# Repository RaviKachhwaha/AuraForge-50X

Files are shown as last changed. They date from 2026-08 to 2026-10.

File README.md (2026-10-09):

<h1 align="center">
  <br>
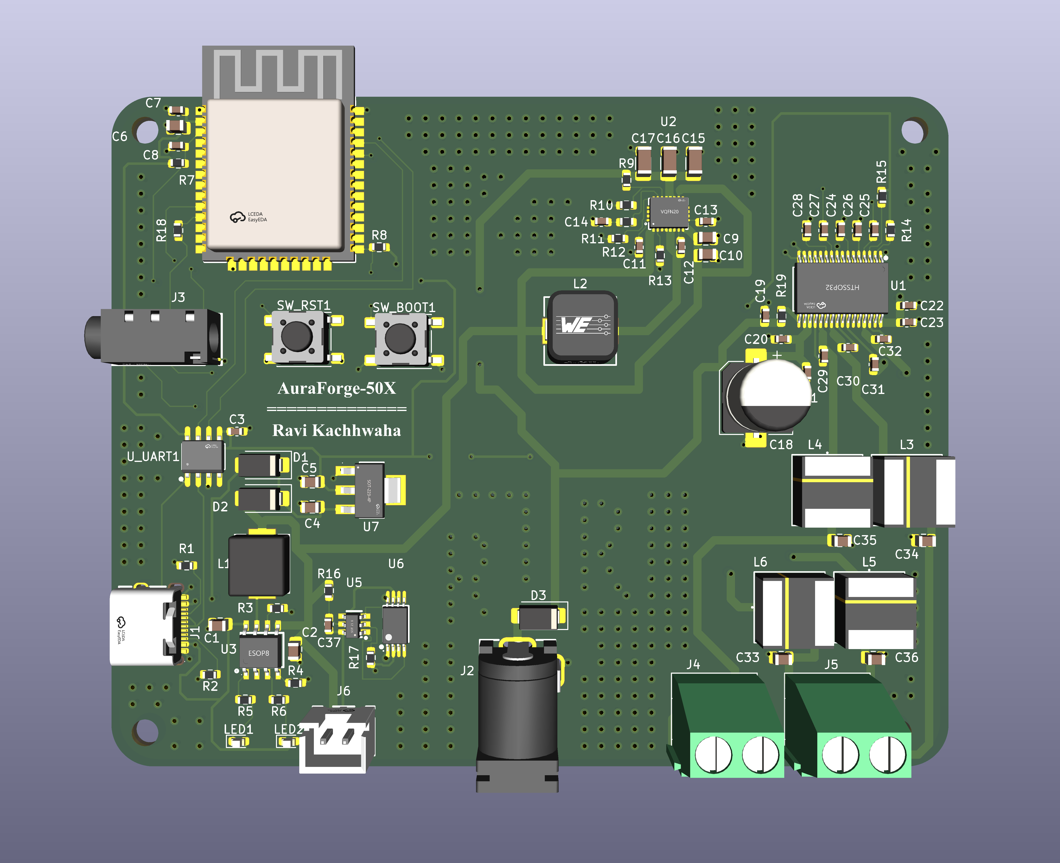
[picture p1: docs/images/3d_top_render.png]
  

  <br>
  AuraForge-50X
  <br>
</h1>
<h3 align="center">
A fully open-sourced complete wireless sound computer. 
</h3>

| Front Render | Back Render | 
| --- | --- |
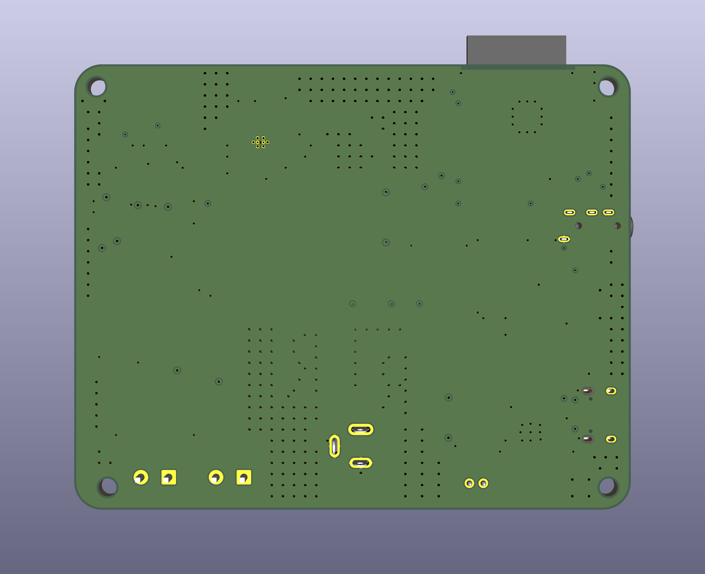
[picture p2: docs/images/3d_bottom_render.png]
|  |  | 

## Schematics  

Here are the schematic design,

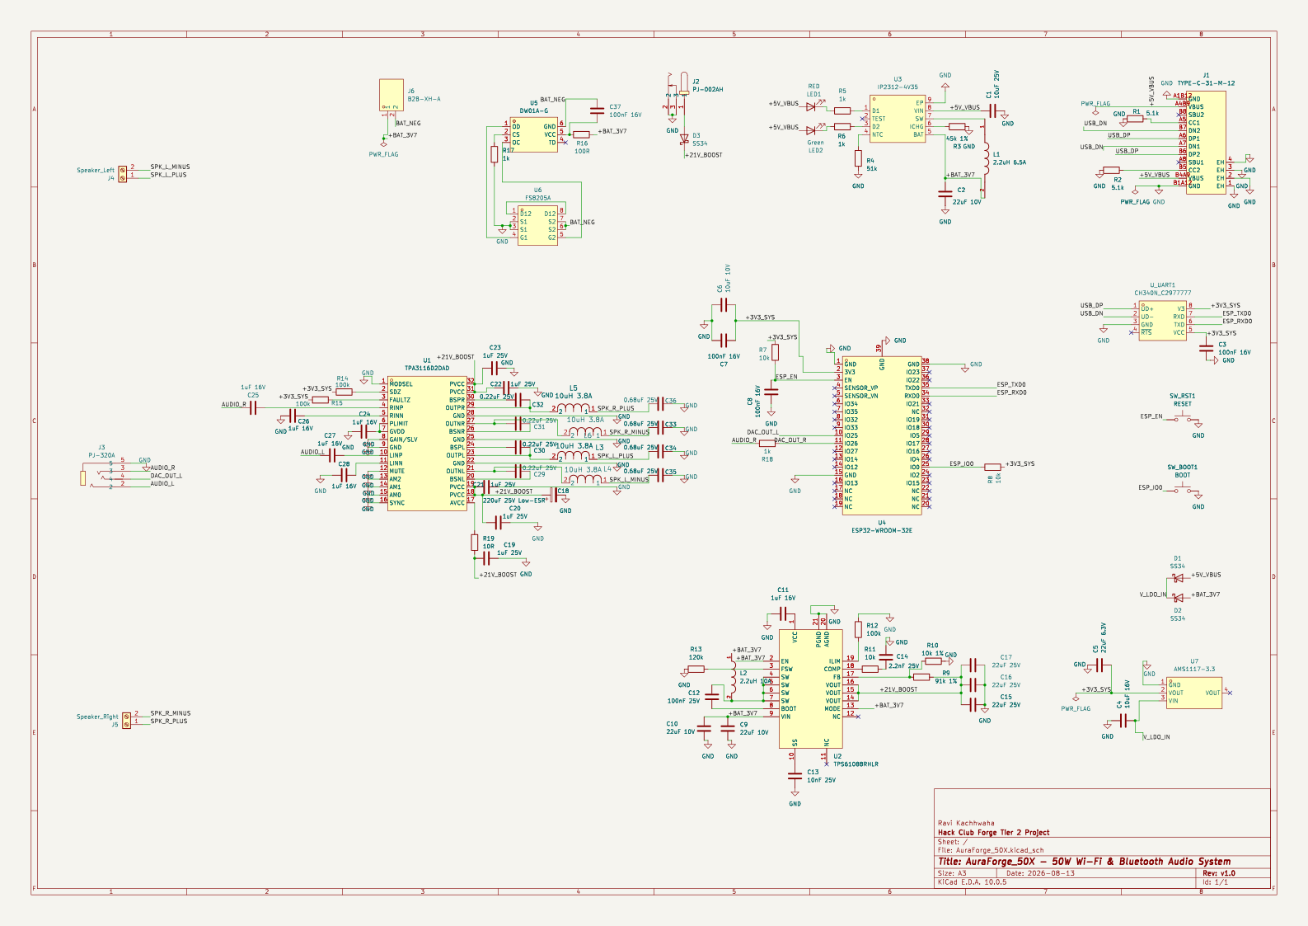
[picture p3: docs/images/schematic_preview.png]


## Features
- **ESP32-WROOM-32E MCU** - Dual-core Xtensa LX6, adjustable from 80 MHz to 240 MHz.
- **A 50Hz Wi-Fi CSI radar and real time DSP**.
- **TPA3116D2 Class-D amp**.
- **3A fast charging with BMS and Li-ion/LiPo both Battery support**.
- Power and battery indicator LED.
- Cyberpunk Web HUD.
- **USB C** - for programming.
- A 12-21V DC jack for power.

## PCB Design 
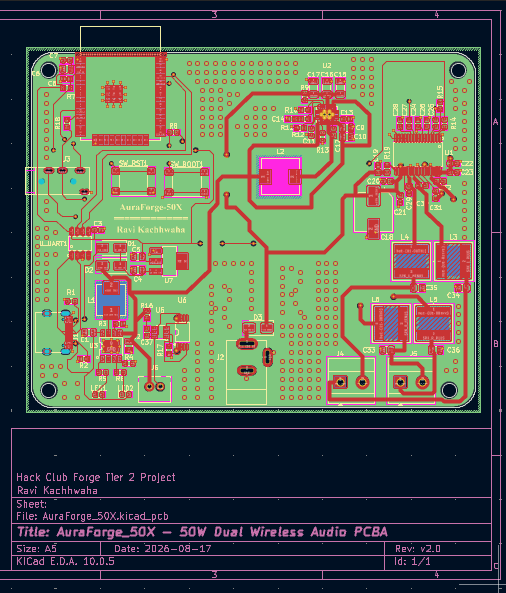
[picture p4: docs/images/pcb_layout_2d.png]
|  |
|--- |  

 ### The PCB is 4 layers with dimensions 100x80mm, made to be easily useable for anyone.  

 ### All the PCB files are [here](https://github.com/RaviKachhwaha/AuraForge-50X/blob/main/hardware) 

| Front Layer | Inner Layer 1 |
| --- | --- |
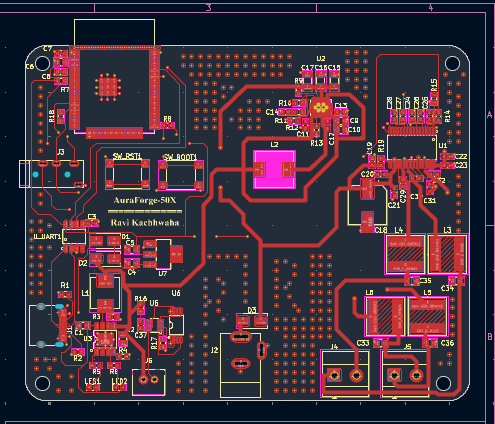
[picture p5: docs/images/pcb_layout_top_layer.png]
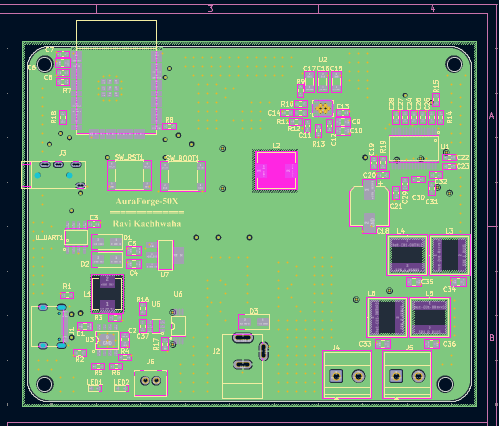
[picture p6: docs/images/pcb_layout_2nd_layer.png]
|  |  |
| Inner Layer 2 | Bottom layer |
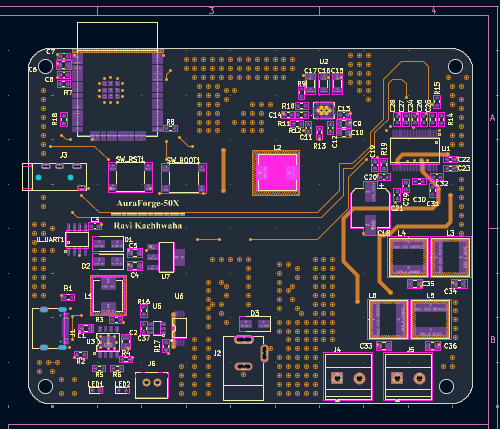
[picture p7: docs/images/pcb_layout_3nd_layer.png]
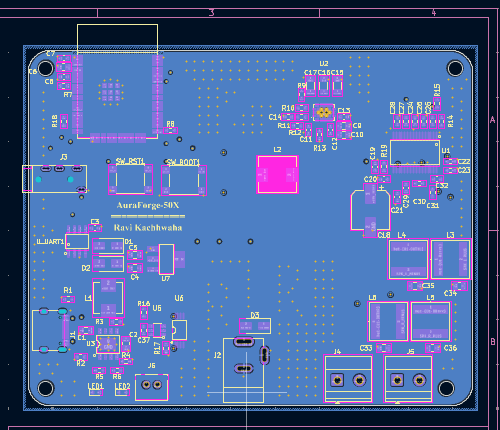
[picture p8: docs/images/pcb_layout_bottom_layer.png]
|  |  |

## Pinout  

This is a general pinout 

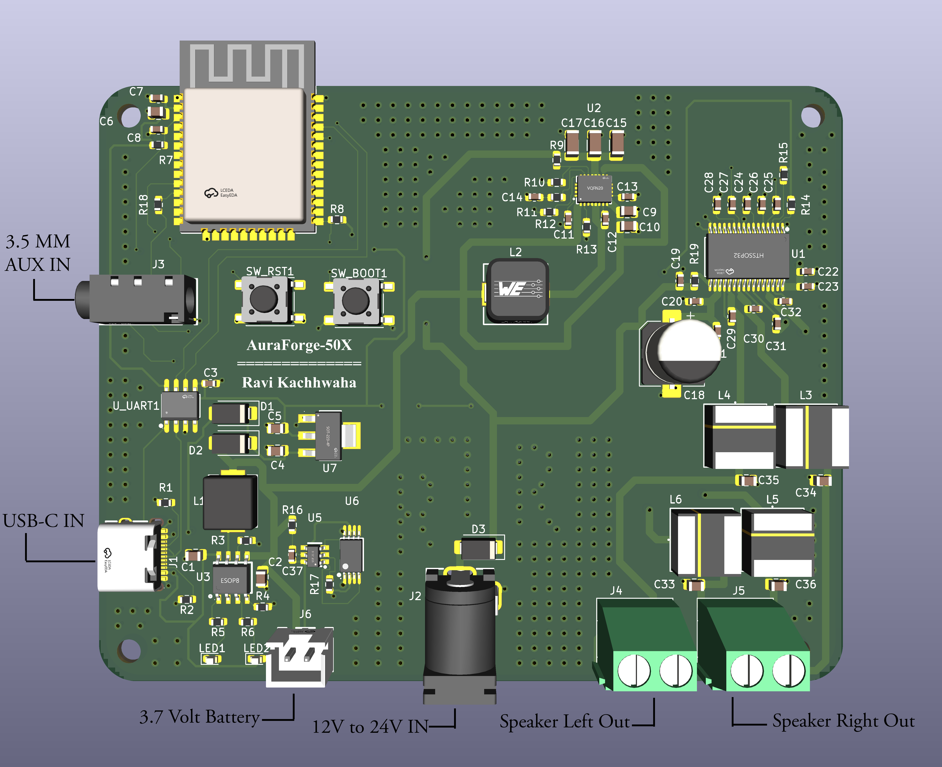
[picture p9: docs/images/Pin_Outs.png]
|  | 
| --- | 

(Credits to the KiCad EDA for KICAD 10, Espressif Systems for the MCU, RuView for CSI processing and Hack Club for fund to make this possible.) 

(Thanks to Madhav, tty7 to review my Design and tell me some mistakes like the antenna is pleased on board without open air due to that the range of it is low after the review from them I places the antenna in open air to get full range of Bluetooth and correct Wi-Fi CSI) 

## Why was it made?  

While using the normal Bluetooth amp for my many projects and in daily need, I realised it doesn't have Wi-Fi and high power support and I couldn't use it, unfortunately I had to think to buy a different high power amp then I see that those have high power but not Wi-Fi support and use very low price components which give low quality, but now I designed one with the simplicity of ESP32-WROOM-32E with being able to use Wi-Fi and Bluetooth both and also Programing support in a same board with high quality audio support for amp IC and have too many features.

## How you can get one for yourself? 

That is pretty easy, you have all the files you will need in the production folder, order the development  
board from any PCB fab ( I chose PCB Power cause its cheap in India and has good quality and also made in India ) and BINGO! You will have it to use for any purpose you want!  

## How do you use it?  
You can use it as any normal amp board but first want to flash the firmware which is given in firmware folder, for flashing you need to first enter the boootloader mode by holding the BOOT buttom and one time press and release the RESET button while connecting to your device, flash it with firmware and after all flashing done press the RESET button one time and you are good to go!
I have attached a simple firmware to start with prebuild firmware available in the firmware folder.  

## BOM  
|Name|Purpose |Quantity|Total Cost (USD)|Link |Distributor|
|----|---|---|---|---|---|
|PCBA|Board and Assembly|2 |62.12 |[Lion Circuits](lioncircuits.com)|Lion Circuits |
|Electronic Components|BOM Component Sourcing|2 |117.00 |[Lion Circuits](lioncircuits.com)|Lion Circuits |
|2 Components|2 BOM Component Sourcing which is not got from Lion Circuits|2 |2.59 |[Sharvi Electronics](sharvielectronics.com)|Sharvi Electronics |
|Battery|18650 3.7V 3000mAh Li-ion Battery with Connector for testing|1 |5.00 |[18650 Battery](https://www.amazon.in/gp/product/B0HBPWY1CS/ref=ox_sc_act_title_3?smid=AJWV8HAM5L3YL&psc=1)|Amazon India |
|Speaker|5 Inch 4 Ohm 25W Full-Range Woofer Speaker (Stereo Pair) for testing|1 |5.48 |[5 Inch Speaker](https://www.amazon.in/gp/product/B0D8CVNZVK/ref=ox_sc_act_title_2?smid=A3C7Z4RVM9A3G1&psc=1)| Amazon India |
|Data & Power Cable|100W USB-C to USB-C Silicone Cable (3ft / 1.0m) for uploading firmware|1 |5.00 |[USB-C Cable](https://www.amazon.in/gp/product/B0F316KC1Q/ref=ox_sc_act_title_4?smid=AJ6SIZC8YQDZX&psc=1)| Amazon India |
|Speaker connection Cable|20 Meter speaker wiring Cable (64ft / 20.0m) for connecting the speakers and testing|1 |3.10 |[20 Meter Wire](https://www.amazon.in/gp/product/B0CHBFB5H2/ref=ox_sc_act_title_1?smid=A2LH9DQUAZIHP2&psc=1)| Amazon India |
|Aux Cable|5 Meter Aux Cable for testing the 3.5 mm Aux jack and wired audio input system|1 |2.70 |[5 Meter Aux Cable](https://www.amazon.in/gp/product/B08XBFV4VR/ref=ox_sc_act_title_2?smid=A2LH9DQUAZIHP2&psc=1)| Amazon India |
|Power Supply|20 Volt Power supply to run the board on its high power to test all things is working on its full power|1 |5.55 |[20V Power Supply](https://www.amazon.in/gp/product/B0D22W62W9/ref=ox_sc_act_title_1?smid=A2QFGJBWFSGOIU&psc=1)| Amazon India |
|Cable to give power to power supply|1.5 Meter Power Cable to give power to power supply adapter due to it not have cable with it|1 |1.60 |[Main Power cable](https://www.amazon.in/gp/product/B0F9VD5NC5/ref=ox_sc_act_title_1?smid=AJ6SIZC8YQDZX&psc=1)| Amazon India |
| | | Total | 209.85 |

LCSC & DigiKey BOM for the components on board is [here](https://github.com/RaviKachhwaha/AuraForge-50X/blob/main/components_bom.csv)

!!Thanks to ALL!!

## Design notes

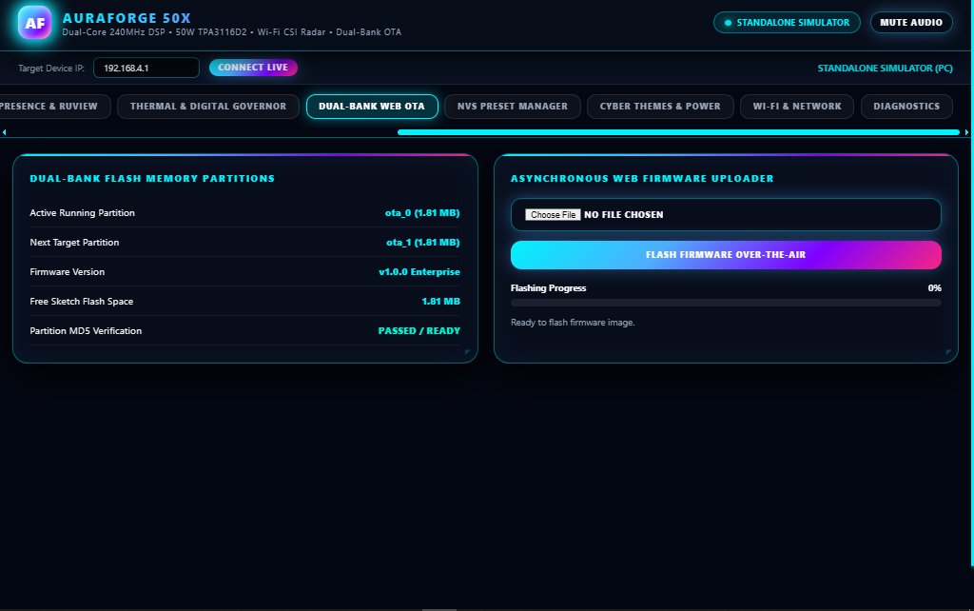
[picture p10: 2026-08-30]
docs/images/UI main page first view 7.png

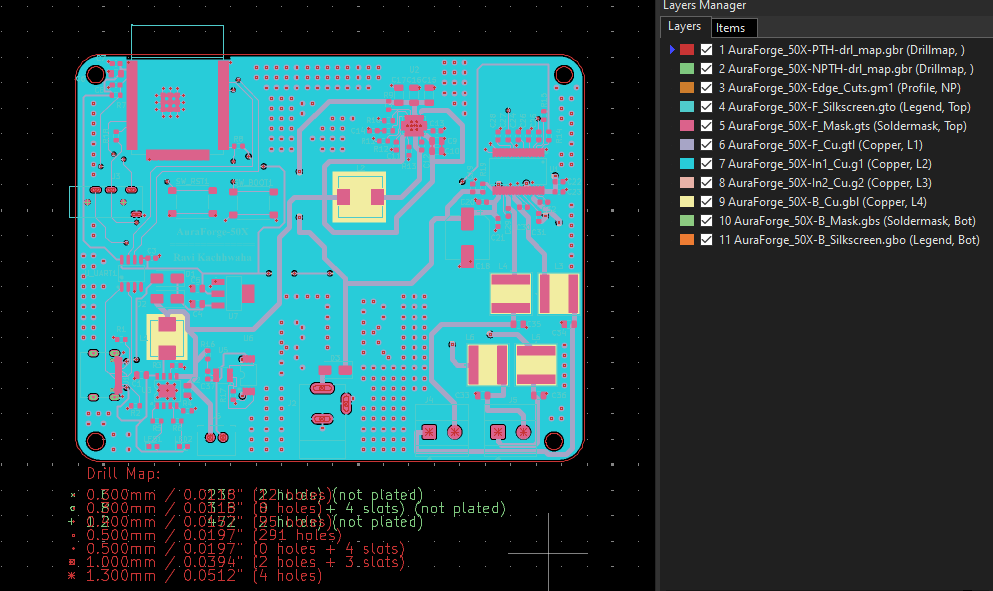
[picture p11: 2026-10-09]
docs/images/Gerber Files Images.png

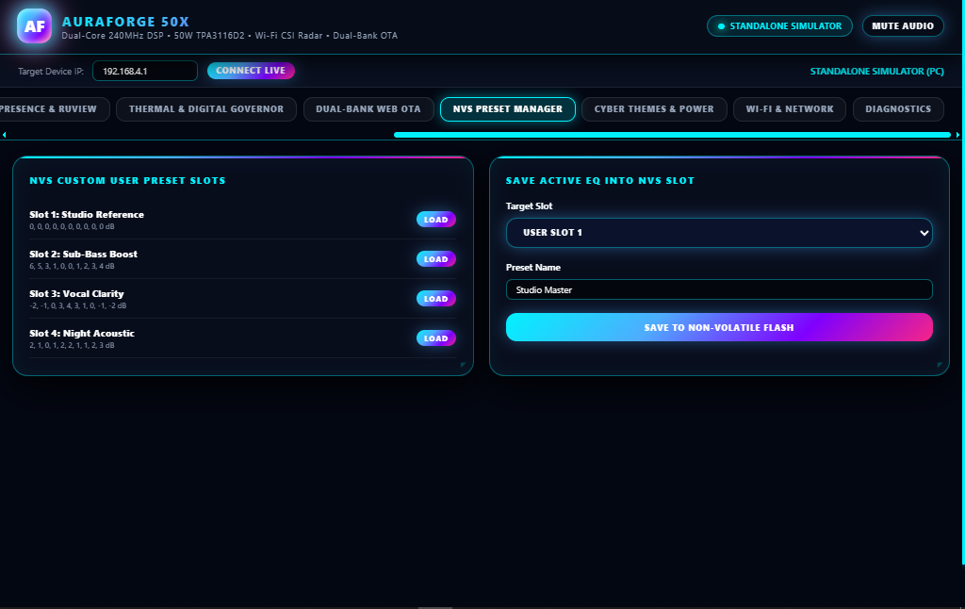
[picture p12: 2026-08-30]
docs/images/UI main page first view 8.png

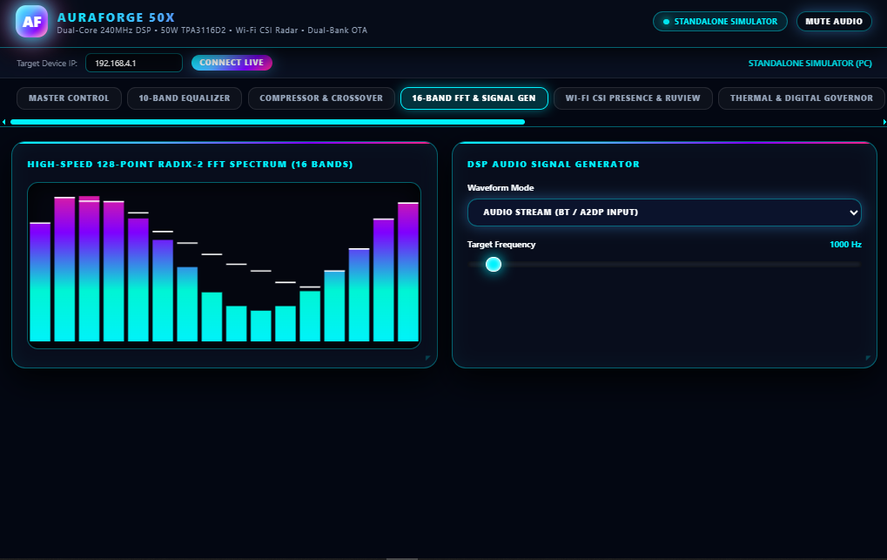
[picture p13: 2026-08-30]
docs/images/UI main page first view 4.png

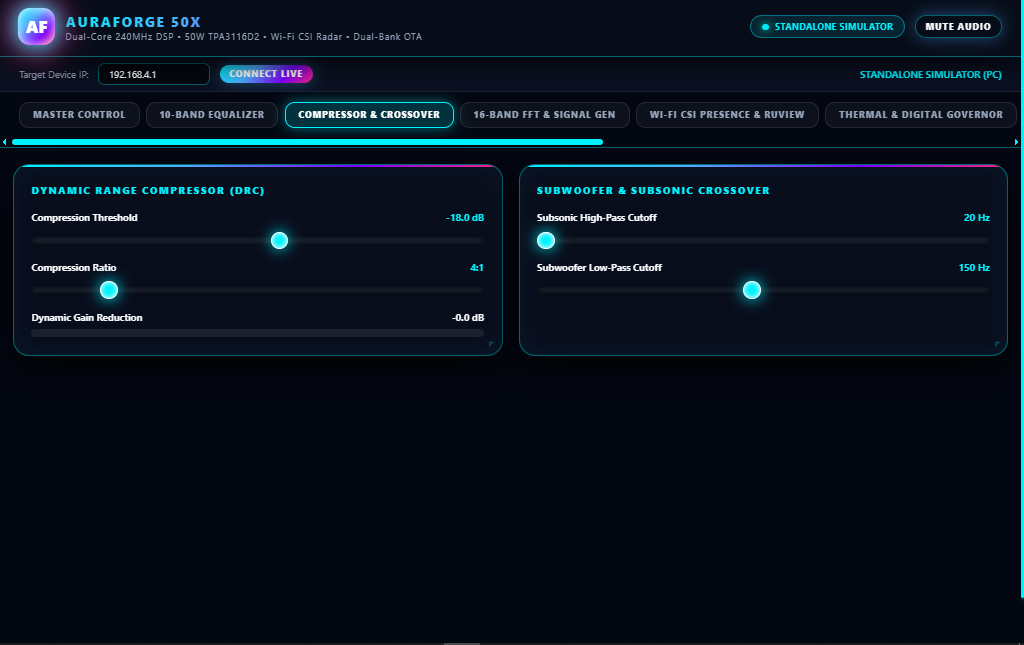
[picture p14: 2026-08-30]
docs/images/UI main page first view 3.png

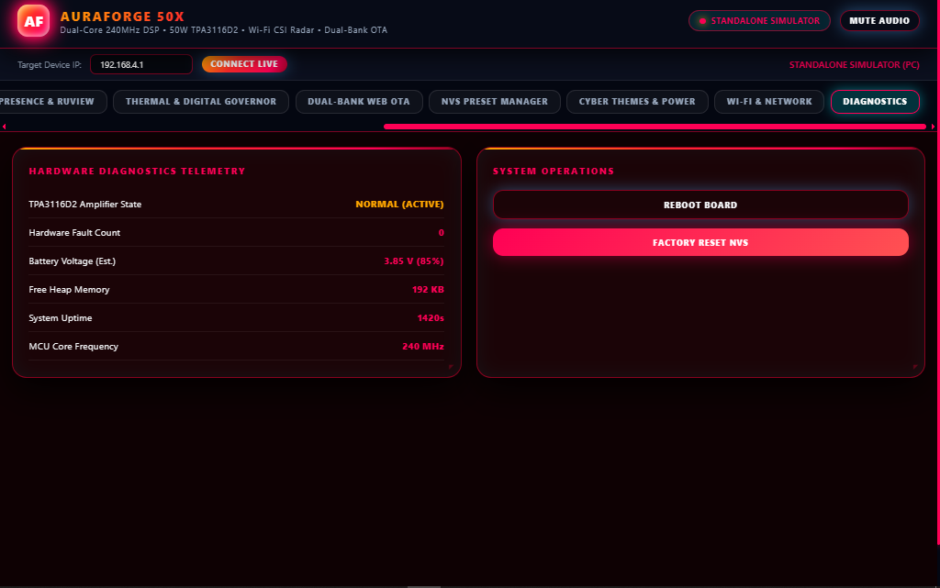
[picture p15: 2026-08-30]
docs/images/UI main page first view 11.png

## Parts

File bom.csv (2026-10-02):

Item # | Category | Description | Qty | Total Price (₹) | Total Price ($) | Supplier / Platform | Reference File / Sourcing Link
1 | Turnkey PCB & PCBA | PCB Fabrication (2 pcs 4-Layer) + SMT Assembly Setup & Mounting (Invoice Net Total incl. GST) | 2 | 10617.00 | 111.32 | pcbpower.com | https://www.pcbpower.com/
2 | Electronic Components | BOM Component Sourcing on pcbpower (On all 45 unique MPNs order will give some discount around 2% to 15% due to that the amount is less then 2 full board componentsm in this amount I applyed the discount amount and this is the total amount of 2 boards components) | 2 | 7221.19 | 75.20 | pcbpower.com / DigiKey | components_bom.csv
3 | Battery Power | Ultra Fast Charging 18650 3.7V 3000mAh Li-ion Battery with Connector | 1 | 322.00 | 3.35 | Amazon India | https://www.amazon.in/gp/product/B0GJPDVB8L/ref=ox_sc_act_title_2?smid=A2FGC2POOS3TS8&psc=1
4 | Acoustic Transducers | Electronic Spices 5 Inch 4 Ohm 25W Full-Range Woofer Speaker (Stereo Pair) | 1 | 408.35 | 4.24 | Amazon India | https://www.amazon.in/gp/product/B0BN44KVVL/ref=ox_sc_act_title_1?smid=A1UUD7CBBVVXIG&psc=1
5 | Data & Power Cable | Anker PowerLine III Flow 100W USB-C to USB-C Silicone Cable (3ft / 1.0m) | 1 | 536.45 | 5.57 | Amazon India | https://www.amazon.in/gp/product/B0F316KC1Q/ref=ox_sc_act_title_3?smid=AJ6SIZC8YQDZX&psc=1
 | TOTAL | Complete AuraForge 50X Prototype Kit (3 Bare PCBs + PCBA Assembly + Components + Peripherals) |  | 19159.30 | 199.68

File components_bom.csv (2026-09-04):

Item # | Reference | Qty | Value | Description | Footprint | Manufacturer | MPN | LCSC Part | Unit Price (₹) | Unit Price ($) | Total Price (₹) | Total Price ($) | Supplier Link
1 | C1 | 1 | 10uF 25V | MLCC Ceramic Capacitor 10uF 25V X7S 0805 for Boost/Buck Input Filtering | Capacitor_SMD:C_0805_2012Metric | TDK | C2012X7S1E106K125AC |  | 56.37 | 0.5911 | 56.37 | 0.59 | https://www.digikey.in/en/products/detail/tdk/C2012X7S1E106K125AC/9991385
2 | C2, C9, C10 | 3 | 22uF 10V | MLCC Ceramic Capacitor 22uF 10V X5R 0805 for 3.3V/5V Rail Bulk Decoupling | Capacitor_SMD:C_0805_2012Metric | Yageo | CC0805MKX5R6BB226 |  | 44.91 | 0.4709 | 134.73 | 1.41 | https://www.digikey.in/en/products/detail/yageo/CC0805MKX5R6BB226/5195306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
3 | C3, C7, C8, C37 | 4 | 100nF 16V | MLCC Ceramic Capacitor 100nF 16V X7R 0603 High-Frequency Bypass Decoupling | Capacitor_SMD:C_0603_1608Metric | Yageo | CC0603KRX7R7BB104 |  | 9.56 | 0.1002 | 38.24 | 0.40 | https://www.digikey.in/en/products/detail/yageo/CC0603KRX7R7BB104/302822
4 | C4 | 1 | 10uF 16V | MLCC Ceramic Capacitor 10uF 16V X5R 0805 Power Rail Decoupling | Capacitor_SMD:C_0805_2012Metric | Yageo | CC0805KRX5R7BB106 |  | 60.20 | 0.6312 | 60.20 | 0.63 | https://www.digikey.in/en/products/detail/yageo/CC0805KRX5R7BB106/7164386
5 | C5 | 1 | 22uF 6.3V | MLCC Ceramic Capacitor 22uF 6.3V X5R 0805 Low-Voltage Rail Filter | Capacitor_SMD:C_0805_2012Metric | Yageo | CC0805MKX5R5BB226 |  | 40.13 | 0.4208 | 40.13 | 0.42 | https://www.digikey.in/en/products/detail/yageo/CC0805MKX5R5BB226/2833629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
6 | C6 | 1 | 10uF 10V | MLCC Ceramic Capacitor 10uF 10V X5R 0805 LDO Output Filter | Capacitor_SMD:C_0805_2012Metric | Yageo | CC0805KRX5R6BB106 |  | 51.60 | 0.5411 | 51.60 | 0.54 | https://www.digikey.in/en/products/detail/yageo/CC0805KRX5R6BB106/5884181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
7 | C11, C24, C25, C26, C27, C28 | 6 | 1uF 16V | MLCC Ceramic Capacitor 1uF 16V X7R 0603 AC Audio Input Coupling & Decoupling | Capacitor_SMD:C_0603_1608Metric | Yageo | CC0603KRX7R7BB105 |  | 16.24 | 0.1703 | 97.44 | 1.02 | https://www.digikey.in/en/products/detail/yageo/CC0603KRX7R7BB105/2833611
8 | C12 | 1 | 100nF 25V | MLCC Ceramic Capacitor 100nF 25V X7R 0603 High-Voltage Bootstrap Bypass | Capacitor_SMD:C_0603_1608Metric | Yageo | CC0603KRX7R8BB104 |  | 9.56 | 0.1002 | 9.56 | 0.10 | https://www.digikey.in/en/products/detail/yageo/CC0603KRX7R8BB104/2103079
9 | C13 | 1 | 10nF 25V | MLCC Ceramic Capacitor 10nF 25V X7R 0603 Snubber & High-Frequency Filter | Capacitor_SMD:C_0603_1608Metric | Yageo | CC0603KRX7R8BB103 |  | 9.56 | 0.1002 | 9.56 | 0.10 | https://www.digikey.in/en/products/detail/yageo/CC0603KRX7R8BB103/2103098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
10 | C14 | 1 | 2.2nF 25V | MLCC Ceramic Capacitor 2.2nF 25V X7R 0603 Filter & Timing Network | Capacitor_SMD:C_0603_1608Metric | Yageo | CC0603KRX7R8BB222 |  | 9.56 | 0.1002 | 9.56 | 0.10 | https://www.digikey.in/en/products/detail/yageo/CC0603KRX7R8BB222/2345066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
11 | C15, C16, C17 | 3 | 22uF 25V | MLCC Ceramic Capacitor 22uF 25V X5R 1206 High-Voltage Output Filter | Capacitor_SMD:C_1206_3216Metric | Samsung | CL31A226KAHNNNE |  | 36.31 | 0.3807 | 108.93 | 1.14 | https://www.digikey.in/en/products/detail/samsung-electro-mechanics/CL31A226KAHNNNE/3888705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
12 | C18 | 1 | 220uF 25V Radial 8x10.5 | Aluminum Electrolytic Capacitor 220uF 25V Radial 8x10.5mm for Power Stage Reservoir | Capacitor_SMD:CP_Elec_8x10.5 | Würth Elektronik | 865060453007 |  | 69.75 | 0.7314 | 69.75 | 0.73 | https://www.digikey.in/en/products/detail/w%C3%BCrth-elektronik/865060453007/5728131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
13 | C19, C20, C21, C22, C23 | 5 | 1uF 25V | MLCC Ceramic Capacitor 1uF 25V X7R 0603 Bootstrap & Bias Decoupling | Capacitor_SMD:C_0603_1608Metric | Yageo | CC0603KPX7R8BB105 |  | 9.62 | 0.1009 | 48.10 | 0.50 | https://www.digikey.in/en/products/detail/yageo/CC0603KPX7R8BB105/12756388
14 | C29, C30, C31, C32 | 4 | 0.22uF 25V | MLCC Ceramic Capacitor 0.22uF 25V X7R 0603 Bootstrap Capacitors for Class-D Stage | Capacitor_SMD:C_0603_1608Metric | Yageo | CC0603KRX7R8BB224 |  | 15.29 | 0.1603 | 61.16 | 0.64 | https://www.digikey.in/en/products/detail/yageo/CC0603KRX7R8BB224/5195211
15 | C33, C34, C35, C36 | 4 | 0.68uF 25V | MLCC Ceramic Capacitor 0.68uF 25V X7R 0805 LC Output Filter Reconstruction | Capacitor_SMD:C_0805_2012Metric | Yageo | CC0805KKX7R9BB684 |  | 27.71 | 0.2906 | 110.84 | 1.16 | https://www.digikey.in/en/products/detail/yageo/CC0805KKX7R9BB684/11491258
16 | D1, D2, D3 | 3 | SS34 (3A 40V) | Schottky Barrier Diode 3A 40V SMA for Reverse Polarity & Power Path Protection | Diode_SMD:D_SMA | onsemi | MBRA340T3G |  | 90.77 | 0.9518 | 272.31 | 2.86 | https://www.digikey.in/en/products/detail/onsemi/MBRA340T3G/918606
17 | J1 | 1 | TYPE-C-31-M-12 | USB Type-C 16-Pin Receptacle with SMT + Through-Hole Shield Tabs for Power & Flashing | easyeda2kicad:USB-C_SMD-TYPE-C-31-M-12_1 | GCT | USB4105-GF-A | C165948 | 76.44 | 0.8015 | 76.44 | 0.80 | https://www.digikey.in/en/products/detail/gct/USB4105-GF-A/11198441
18 | J2 | 1 | PJ-002AH | DC Power Barrel Jack 5.5mm x 2.1mm Through-Hole for 12V-21V External Power Input | easyeda2kicad:DC-IN-TH_PJ-002AH | CUI Devices | PJ-002AH | C2961147 | 67.84 | 0.7113 | 67.84 | 0.71 | https://www.digikey.in/en/products/detail/same-sky-formerly-cui-devices/PJ-002AH/408446
19 | J3 | 1 | PJ-320A | 3.5mm Stereo Audio Headphone Jack 5-Pin Through-Hole Connector | easyeda2kicad:AUDIO-TH_XKB_PJ-320A | CUI Devices | SJ-3524-SMT-TR | C2884926 | 85.04 | 0.8917 | 85.04 | 0.89 | https://www.digikey.in/en/products/detail/same-sky-formerly-cui-devices/SJ-3524-SMT-TR/281298
20 | J4, J5 | 2 | Speaker_Terminal | 2-Pin 5.08mm Pitch Screw Terminal Block for Left & Right Speaker Output Connections | TerminalBlock_Phoenix:TerminalBlock_Phoenix_MKDS-1,5-2_1x02_P5.00mm_Horizontal | Phoenix Contact | 1715721 |  | 110.84 | 1.1622 | 221.68 | 2.32 | https://www.digikey.in/en/products/detail/phoenix-contact/1715721/260631?s=N4IgTCBcDaIIwHY4FYFjiAugXyA
21 | J6 | 1 | B2B-XH-A | 2-Pin 2.5mm Pitch JST-XH Keyed Battery Connector for 3.7V Li-ion Connection | easyeda2kicad:CONN-TH_B2B-XH-A-LF-SN | JST | B2B-XH-A(LF)(SN) | C158012 | 9.56 | 0.1002 | 9.56 | 0.10 | https://www.digikey.in/en/products/detail/jst-sales-america-inc/B2B-XH-A/1651045
22 | L1 | 1 | 2.2uH 6.5A | Shielded Power Inductor 2.2uH 6.5A SMD 7.3x7.3mm for IP2312 3A Buck Charger | Inductor_SMD:L_7.3x7.3_H4.5 | Shenzhen Sunlord Electronics Co. Ltd. | MWSA0603S-2R2MT |  | 93.64 | 0.9819 | 93.64 | 0.98 | https://www.digikey.in/en/products/detail/shenzhen-sunlord-electronics-co-ltd/MWSA0603S-2R2MT/14120106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
23 | L2 | 1 | 2.2uH 10.0A | High-Current Shielded Power Inductor 2.2uH 10.0A SMD 10.4x10.4mm for TPS61088 Boost | Inductor_SMD:L_10.4x10.4_H4.8 | Wurth Elektronik | 7443340220 |  | 204.48 | 2.1441 | 204.48 | 2.14 | https://www.digikey.in/en/products/detail/w%C3%BCrth-elektronik/7443340220/2175580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
24 | L3, L4, L5, L6 | 4 | 10uH 3.8A | Shielded Power Inductors 10uH 3.8A SMD 8.0x8.0mm for TPA3116D2 LC Output Filter | Inductor_SMD:L_Taiyo-Yuden_NR-80xx | Taiyo Yuden | NRS8040T100MJGJ |  | 33.44 | 0.3506 | 133.76 | 1.40 | https://www.digikey.in/en/products/detail/taiyo-yuden/NRS8040T100MJGJ/2666010
25 | LED1 | 1 | Red LED (Charge) | Surface Mount Red LED 0603 Indicator for Battery Charging Status | LED_SMD:LED_0603_1608Metric | Kingbright | APT1608SURCK |  | 20.06 | 0.2103 | 20.06 | 0.21 | https://www.digikey.in/en/products/detail/kingbright/APT1608SURCK/1747522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
26 | LED2 | 1 | Green LED (Done) | Surface Mount Green LED 0603 Indicator for Charge Complete / Standby Status | LED_SMD:LED_0603_1608Metric | Kingbright | APT1608ZGC |  | 60.20 | 0.6312 | 60.20 | 0.63 | https://www.digikey.in/en/products/detail/kingbright/APT1608ZGC/1747525
27 | R1, R2 | 2 | 5.1k 1% | Thick Film Chip Resistor 5.1k Ohm 1% 0603 for USB Type-C CC1/CC2 Pull-Down Configuration | Resistor_SMD:R_0603_1608Metric | Yageo | RC0603FR-135K1L |  | 9.56 | 0.1002 | 19.12 | 0.20 | https://www.digikey.in/en/products/detail/yageo/RC0603FR-135K1L/14008317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
28 | R3 | 1 | 45.3k 1% | Thick Film Chip Resistor 45.3k Ohm 1% 0603 for Fast Charger Configuration | Resistor_SMD:R_0603_1608Metric | Yageo | RC0603FR-0745K3L |  | 9.56 | 0.1002 | 9.56 | 0.10 | https://www.digikey.in/en/products/detail/yageo/RC0603FR-0745K3L/727245
29 | R4 | 1 | 51k 1% | Thick Film Chip Resistor 51k Ohm 1% 0603 for Status & Bias Circuitry | Resistor_SMD:R_0603_1608Metric | Yageo | RC0603FR-1351KL |  | 9.56 | 0.1002 | 9.56 | 0.10 | https://www.digikey.in/en/products/detail/yageo/RC0603FR-1351KL/14286485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
30 | R5, R6, R17, R18 | 4 | 1k 1% | Thick Film Chip Resistor 1k Ohm 1% 0603 for LED Current Limiting & Bias | Resistor_SMD:R_0603_1608Metric | Yageo | RC0603FR-071KL |  | 9.56 | 0.1002 | 38.24 | 0.40 | https://www.digikey.in/en/products/detail/yageo/RC0603FR-071KL/726843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
31 | R7, R8, R10, R11 | 4 | 10k 1% | Thick Film Chip Resistor 10k Ohm 1% 0603 for I2C/Pull-up/Feedback Divider Networks | Resistor_SMD:R_0603_1608Metric | Yageo | RC0603FR-0710KL |  | 9.56 | 0.1002 | 38.24 | 0.40 | https://www.digikey.in/en/products/detail/yageo/RC0603FR-0710KL/726880
32 | R9 | 1 | 91k 1% | Thick Film Chip Resistor 91k Ohm 1% 0603 for TPS61088 12.0V Feedback Voltage Divider | Resistor_SMD:R_0603_1608Metric | Yageo | RC0603FR-0791KL |  | 9.56 | 0.1002 | 9.56 | 0.10 | https://www.digikey.in/en/products/detail/yageo/RC0603FR-0791KL/727428
33 | R12, R14, R15 | 3 | 100k 1% | Thick Film Chip Resistor 100k Ohm 1% 0603 for Enable & High-Impedance Pull-up Networks | Resistor_SMD:R_0603_1608Metric | Yageo | RC0603FR-07100KL |  | 9.56 | 0.1002 | 28.68 | 0.30 | https://www.digikey.in/en/products/detail/yageo/RC0603FR-07100KL/726889
34 | R13 | 1 | 120k 1% | Thick Film Chip Resistor 120k Ohm 1% 0603 for Switching Frequency Configuration | Resistor_SMD:R_0603_1608Metric | Yageo | RC0603FR-07120KL |  | 9.56 | 0.1002 | 9.56 | 0.10 | https://www.digikey.in/en/products/detail/yageo/RC0603FR-07120KL/726921
35 | R16 | 1 | 100R 1% | Thick Film Chip Resistor 100 Ohm 1% 0603 for Gate Drive & Snubber Damping | Resistor_SMD:R_0603_1608Metric | Yageo | RC0603FR-07100RL |  | 10.51 | 0.1102 | 10.51 | 0.11 | https://www.digikey.in/en/products/detail/yageo/RC0603FR-07100RL/726888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
36 | R19 | 1 | 10R 1% | Thick Film Chip Resistor 10 Ohm 1% 0603 for Filter Damping & Snubber Network | Resistor_SMD:R_0603_1608Metric | Yageo | RC0603FR-1310RL |  | 9.56 | 0.1002 | 9.56 | 0.10 | https://www.digikey.in/en/products/detail/yageo/RC0603FR-1310RL/13694232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
37 | SW_BOOT1, SW_RST1 | 2 | SMT Tact Switch | SMT Tactile Pushbutton Switch 6.0x3.5mm for Manual Hardware Boot & Reset Controls | Button_Switch_SMD:SW_SPST_PTS645Sx43SMTR92 | C&K | PTS645SL43SMTR92LFS |  | 37.26 | 0.3907 | 74.52 | 0.78 | https://www.digikey.in/en/products/detail/c-k/PTS645SL43SMTR92-LFS/3861373
38 | U1 | 1 | TPA3116D2 50W Amp | Texas Instruments TPA3116D2 50W Stereo Dual BTL Class-D Audio Power Amplifier IC | easyeda2kicad:HTSSOP-32_L11.0-W6.1-P0.65-LS8.1-BL | Texas Instruments | TPA3116D2DADR | C50144 | 304.80 | 3.1960 | 304.80 | 3.20 | https://www.digikey.in/en/products/detail/texas-instruments/TPA3116D2DADR/3305528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
39 | U2 | 1 | TPS61088 10A Boost | Texas Instruments TPS61088 10A High-Efficiency Fully Synchronous Boost Converter IC | easyeda2kicad:VQFN-20_L4.6-W3.6-P0.50-BL | Texas Instruments | TPS61088RHLR | C87357 | 261.81 | 2.7452 | 261.81 | 2.75 | https://www.digikey.in/en/products/detail/texas-instruments/TPS61088RHLR/5253864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
40 | U3 | 1 | IP2312 3A Charger | Injoinic IP2312 3A High-Efficiency Synchronous Step-Down Buck Li-ion Fast Charger IC | easyeda2kicad:ESOP-8_L4.9-W3.9-P1.27-LS6.0-BL-EP | Injoinic | IP2312 | C605433 | 31.49 | 0.3302 | 31.49 | 0.33 | https://www.lcsc.com/product-detail/C605433.html?s_z=n_q_C605433&globalKeyword=C605433
41 | U4 | 1 | ESP32-WROOM-32E | Espressif ESP32-WROOM-32E 240MHz Dual-Core Wi-Fi & Bluetooth DSP/MCU Module | easyeda2kicad:WIFI-SMD_ESP32-WROOM-32E | Espressif Systems | ESP32-WROOM-32E-N4 | C701341 | 476.79 | 4.9994 | 476.79 | 5.00 | https://www.digikey.in/en/products/detail/espressif-systems/ESP32-WROOM-32E-N4/11613125
42 | U5 | 1 | Battery Protection | evvo DW01 One-Cell Lithium-Ion Battery Overcharge/Overdischarge Protection IC | easyeda2kicad:SOT-23-6_L2.9-W1.6-P0.95-LS2.8-BR | evvo | DW01 | C61503 | 10.51 | 0.1102 | 10.51 | 0.11 | https://www.digikey.in/en/products/detail/evvo/DW01/26221073
43 | U6 | 1 | Dual N-MOSFET | Fortune Semi FS8205A Dual N-Channel Power MOSFET for Battery Protection Switch | easyeda2kicad:TSSOP-8_L4.4-W3.0-P0.65-LS6.4-BL-2 | Fortune Semi | FS8205A | C16052 | 62.11 | 0.6513 | 62.11 | 0.65 | https://www.digikey.in/en/products/detail/evvo/FS8205A/26220994?s=N4IgTCBcDaIGIGUAcYAMBWAgiAugXyA
44 | U7 | 1 | 3.3V 1A LDO | onsemi NCP1117ST33T3G 3.3V 1A Positive Low Dropout (LDO) Linear Voltage Regulator | easyeda2kicad:SOT-223-3_L6.5-W3.4-P2.30-LS7.0-BR | onsemi | NCP1117ST33T3G | C6186 | 59.24 | 0.6212 | 59.24 | 0.62 | https://www.digikey.in/en/products/detail/onsemi/NCP1117ST33T3G/1749063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
45 | U_UART1 | 1 | USB-to-UART Bridge | WCH CH340N USB-to-Serial UART Bridge IC for Hardware Firmware Flashing & Serial Telemetry | easyeda2kicad:SOP-8_L4.9-W3.9-P1.27-LS6.0-BL | WCH | CH340N | C2977777 | 64.85 | 0.6800 | 64.85 | 0.68 | https://www.lcsc.com/product-detail/C2977777.html?s_z=n_q_C2977777&globalKeyword=C2977777

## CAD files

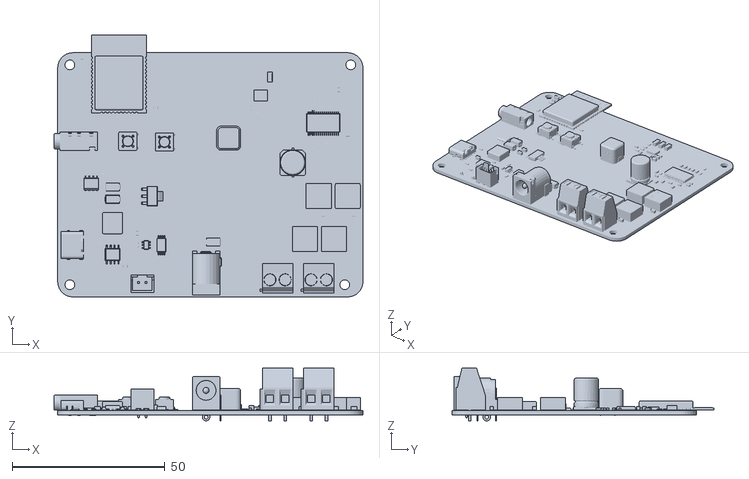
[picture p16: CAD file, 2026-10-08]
hardware/AuraForge_50X-compressed.stl
101.2 x 85.8 x 17.3

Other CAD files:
hardware/AuraForge_50X.step

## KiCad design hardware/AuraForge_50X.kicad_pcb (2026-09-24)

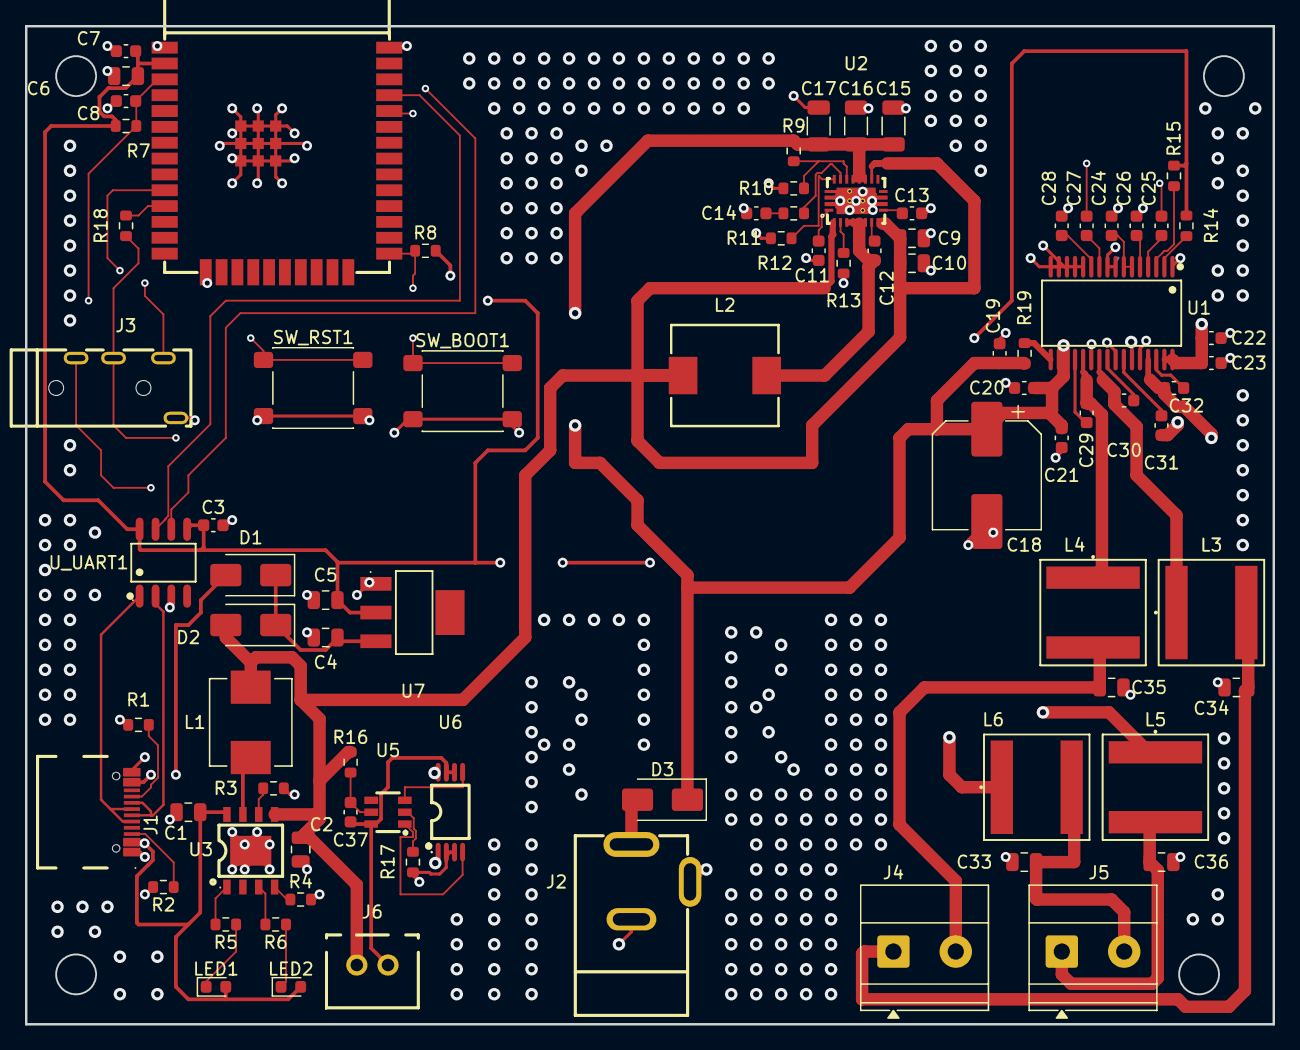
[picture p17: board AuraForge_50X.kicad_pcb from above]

Board: 4 copper layers, 100.0 x 80.0 mm, 83 parts (0 on the bottom side), 61 nets.

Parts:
C1: 10uF 25V; C_0805_2012Metric
C2, C9, C10: 22uF 10V; C_0805_2012Metric
C3, C7, C8, C37: 100nF 16V; C_0603_1608Metric
C4: 10uF 16V; C_0805_2012Metric
C5: 22uF 6.3V; C_0805_2012Metric
C6: 10uF 10V; C_0805_2012Metric
C11, C24, C25, C26, C27, C28: 1uF 16V; C_0603_1608Metric
C12: 100nF 25V; C_0603_1608Metric
C13: 10nF 25V; C_0603_1608Metric
C14: 2.2nF 25V; C_0603_1608Metric
C15, C16, C17: 22uF 25V; C_1206_3216Metric
C18: 220uF 25V Low-ESR; CP_Elec_8x10.5
C19, C20, C21, C22, C23: 1uF 25V; C_0603_1608Metric
C29, C30, C31, C32: 0.22uF 25V; C_0603_1608Metric
C33, C34, C35, C36: 0.68uF 25V; C_0805_2012Metric
D1, D2, D3: SS34; D_SMA
J1: TYPE-C-31-M-12; USB-C_SMD-TYPE-C-31-M-12_1
J2: PJ-002AH; DC-IN-TH_PJ-002AH
J3: PJ-320A; AUDIO-TH_XKB_PJ-320A
J4: Speaker_Left; TerminalBlock_Phoenix_MKDS-1,5-2_1x02_P5.00mm_Horizontal
J5: Speaker_Right; TerminalBlock_Phoenix_MKDS-1,5-2_1x02_P5.00mm_Horizontal
J6: B2B-XH-A; CONN-TH_B2B-XH-A-LF-SN
L1: 2.2uH 6.5A; INDM7066X300N
L2: 2.2uH 10A; WE-HCC_8070
L3, L4, L5, L6: 10uH 3.8A; IND_TAIYO_NRS8040_TAY
LED1: RED; LED_0603_1608Metric
LED2: Green; LED_0603_1608Metric
R1, R2: 5.1k; R_0603_1608Metric
R3: 45k 1%; R_0603_1608Metric
R4: 51k; R_0603_1608Metric
R5, R6, R17, R18: 1k; R_0603_1608Metric
R7, R8, R11: 10k; R_0603_1608Metric
R9: 91k 1%; R_0603_1608Metric
R10: 10k 1%; R_0603_1608Metric
R12, R14, R15: 100k; R_0603_1608Metric
R13: 120k; R_0603_1608Metric
R16: 100R; R_0603_1608Metric
R19: 10R; R_0603_1608Metric
SW_BOOT1: BOOT; SW_SPST_PTS645Sx43SMTR92
SW_RST1: RESET; SW_SPST_PTS645Sx43SMTR92
U1: TPA3116D2DAD; HTSSOP-32_L11.0-W6.1-P0.65-LS8.1-BL
U2: TPS61088RHLR; VQFN-20_L4.6-W3.6-P0.50-BL
U3: IP2312-4V35; ESOP-8_L4.9-W3.9-P1.27-LS6.0-BL-EP
U4: ESP32-WROOM-32E; WIFI-SMD_ESP32-WROOM-32E
U5: DW01A-G; SOT-23-6_L2.9-W1.6-P0.95-LS2.8-BR
U6: FS8205A; TSSOP-8_L4.4-W3.0-P0.65-LS6.4-BL-2
U7: AMS1117-3.3; SOT-223-3_L6.5-W3.4-P2.30-LS7.0-BR
U_UART1: CH340N_C2977777; SOP-8_L4.9-W3.9-P1.27-LS6.0-BL

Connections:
/+3V3_SYS: C3.1, C5.2, C6.2, C7.2, R7.1, R8.2, R14.1, R15.1, U4.2 (3V3), U7.2 (VOUT), U_UART1.5 (VCC), U_UART1.8 (V3)
/+5V_VBUS: C1.1, D1.2 (A), J1.A4B9 (VBUS), J1.B4A9 (VBUS), LED1.2 (A), LED2.2 (A), U3.8 (VIN)
/+21V_BOOST: C15.1, C16.1, C17.1, C18.1, C19.1, C20.1, C21.1, C22.1, C23.1, D3.1 (K), R9.2, R19.1, U1.18 (PVCC), U1.19 (PVCC), U1.31 (PVCC), U1.32 (PVCC), U2.14 (VOUT), U2.15 (VOUT), U2.16 (VOUT)
/+BAT_3V7: C2.1, C9.1, C10.2, D2.2 (A), J6.1, L1.2, L2.1, R16.2, U2.2 (EN), U2.9 (VIN), U2.13 (MODE), U3.5 (BAT)
/AUDIO_L: C27.1, J3.2
/AUDIO_R: C25.1, J3.3, R18.1
/BAT_NEG: C37.1, J6.2, U5.6 (GND), U6.6 (S2), U6.7 (S2)
/DAC_OUT_L: J3.4, U4.10 (IO25)
/DAC_OUT_R: R18.2, U4.11 (IO26)
/ESP_EN: C8.2, R7.2, SW_RST1.1, U4.3 (EN)
/ESP_IO0: R8.1, SW_BOOT1.1, U4.25 (IO0)
/ESP_RXD0: U4.34 (RXD0), U_UART1.6 (TXD)
/ESP_TXD0: U4.35 (TXD0), U_UART1.7 (RXD)
/SPK_L_MINUS: C35.1, J4.2, L4.2
/SPK_L_PLUS: C34.1, J4.1, L3.2
/SPK_R_MINUS: C33.1, J5.2, L6.2
/SPK_R_PLUS: C36.1, J5.1, L5.2
/USB_DN: J1.A7 (DN1), J1.B7 (DN2), U_UART1.2 (UD-)
/USB_DP: J1.A6 (DP1), J1.B6 (DP2), U_UART1.1 (UD+)
/V_LDO_IN: C4.2, D1.1 (K), D2.1 (K), U7.3 (VIN)
GND: C1.2, C2.2, C3.2, C4.1, C5.1, C6.1, C7.1, C8.1, C9.2, C10.1, C11.1, C13.2, C14.2, C15.2, C16.2, C17.2, C18.2, C19.2, C20.2, C21.2, C22.2, C23.2, C24.1, C26.1, C28.1, C33.2, C34.2, C35.2, C36.2, J1.A1B12 (GND), J1.B1A12 (GND), J2.2, J2.3, J3.5, R1.2, R2.2, R3.2, R4.2, R10.2, R12.1, R13.1, R17.2, SW_BOOT1.2, SW_RST1.2, U1.1 (MODSEL), U1.8 (GAIN/SLV), U1.9 (GND), U1.12 (MUTE), U1.13 (AM2), U1.14 (AM1), U1.15 (AM0), U1.16 (SYNC), U1.22 (GND), U1.25 (GND), U1.28 (GND), U2.20 (AGND), U2.21 (PGND), U3.9 (EP), U4.1 (GND), U4.15 (GND), U4.38 (GND), U4.39 (GND), U6.2 (S1), U6.3 (S1), U7.1 (GND), U_UART1.3 (GND)
unnamed: C12.2, L2.2, U2.4 (SW), U2.5 (SW), U2.6 (SW), U2.7 (SW)
unnamed: C14.1, R11.2
unnamed: D3.2 (A), J2.1
unnamed: J1.A5 (CC1), R1.1
unnamed: J1.B5 (CC2), R2.1
unnamed: LED1.1 (K), R5.1
unnamed: LED2.1 (K), R6.1
unnamed: R19.2, U1.17 (AVCC)
unnamed: C29.2, U1.20 (BSNL)
unnamed: C31.2, U1.26 (BSNR)
unnamed: C30.1, U1.24 (BSPL)
unnamed: C32.1, U1.30 (BSPR)
unnamed: R15.2, U1.3 (FAULTZ)
unnamed: C24.2, U1.6 (PLIMIT), U1.7 (GVDD)
unnamed: C28.2, U1.11 (LINN)
unnamed: C27.2, U1.10 (LINP)
unnamed: C29.1, L4.1, U1.21 (OUTNL)
unnamed: C31.1, L6.1, U1.27 (OUTNR)
unnamed: C30.2, L3.1, U1.23 (OUTPL)
unnamed: C32.2, L5.1, U1.29 (OUTPR)
unnamed: C26.2, U1.5 (RINN)
unnamed: C25.2, U1.4 (RINP)
unnamed: R14.2, U1.2 (SDZ)
unnamed: C12.1, U2.8 (BOOT)
unnamed: R11.1, U2.18 (COMP)
unnamed: R9.1, R10.1, U2.17 (FB)
unnamed: R13.2, U2.3 (FSW)
unnamed: R12.2, U2.19 (ILIM)
unnamed: C13.1, U2.10 (SS)
unnamed: C11.2, U2.1 (VCC)
unnamed: R5.2, U3.1 (D1)
unnamed: R6.2, U3.3 (D2)
unnamed: R3.1, U3.6 (ICHG)
unnamed: R4.1, U3.4 (NTC)
unnamed: L1.1, U3.7 (SW)
unnamed: R17.1, U5.2 (CS)
unnamed: U5.3 (OC), U6.5 (G2)
unnamed: U5.1 (OD), U6.4 (G1)
unnamed: C37.2, R16.1, U5.5 (VCC)
unnamed: U6.1 (D12), U6.8 (D12)

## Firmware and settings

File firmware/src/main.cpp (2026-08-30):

/**
 * @file main.cpp
 * @brief AuraForge 50X - Enterprise High-Fidelity Wireless Audio & DSP Station
 * @author Ravi Kachhwaha
 * @license MIT
 */

#include "BluetoothA2DPSink.h"
#include "ConfigManager.h"
#include "CsiRadarEngine.h"
#include "DspEngine.h"
#include "HardwareMonitor.h"
#include "WebServerModule.h"
#include "WifiManagerModule.h"
#include <Arduino.h>
#include <WiFi.h>
#include <driver/i2s.h>

// ==============================================================================
// BLUETOOTH A2DP SINK & AUDIO CALLBACKS
// ==============================================================================
BluetoothA2DPSink *a2dp_sink = nullptr;

void audioDataCallback(const uint8_t *data, uint32_t len) {
  uint32_t sample_count =
      len / 4; // 2 channels * 16-bit (2 bytes) = 4 bytes per frame
  g_dspEngine.processAudioBlock((int16_t *)data, sample_count);
}

void avrcpStateCallback(esp_a2d_connection_state_t state, void *ptr) {
  if (state == ESP_A2D_CONNECTION_STATE_CONNECTED) {
    Serial.println("[AuraForge 50X] Bluetooth Source Connected!");
    g_hardwareMonitor.setLedMode(LED_ON);
  } else if (state == ESP_A2D_CONNECTION_STATE_DISCONNECTED) {
    Serial.println("[AuraForge 50X] Bluetooth Source Disconnected.");
    g_hardwareMonitor.setLedMode(LED_SLOW_BLINK);
  }
}

// ==============================================================================
// SERIAL CLI COMMAND INTERPRETER
// ==============================================================================
void handleSerialCommands() {
  if (!Serial.available())
    return;

  String cmd = Serial.readStringUntil('\n');
  cmd.trim();

  if (cmd.equalsIgnoreCase("status")) {
    Serial.println("--- AuraForge 50X Enterprise System Diagnostics ---");
    Serial.printf(
        "ESP32 Chip Rev: %d | CPU Freq: %d MHz | Silicon Temp: %.1f°C\n",
        ESP.getChipRevision(), ESP.getCpuFreqMHz(),
        g_hardwareMonitor.getTemperatureC());
    Serial.printf("Thermal Governor: %s | Attenuation: %.1f dB\n",
                  g_hardwareMonitor.getGovernorState() == GOVERNOR_NORMAL
                      ? "NORMAL (100% Gain)"
                      : "THROTTLED",
                  g_hardwareMonitor.getTelemetry().thermalAttenuation_dB);
    Serial.printf("Free Heap: %d bytes | Free Sketch Space: %d bytes\n",
                  ESP.getFreeHeap(), ESP.getFreeSketchSpace());
    Serial.printf("Wi-Fi STA: %s (IP: %s) | Wi-Fi AP: %s (IP: %s)\n",
                  g_wifiManager.isConnectedSTA() ? "CONNECTED" : "OFFLINE",
                  g_wifiManager.getLocalIp().c_str(),
                  g_wifiManager.isAPActive() ? "ACTIVE" : "DISABLED",
                  g_wifiManager.getApIp().c_str());
    Serial.printf("CSI Radar Presence: State %d | Motion: %.2f\n",
                  (int)g_csiRadarEngine.getPresenceState(),
                  g_csiRadarEngine.getTelemetry().motionIndex);
    Serial.printf("TPA3116D2 FAULT Pin: %s | Output: %s\n",
                  digitalRead(PIN_AMP_FAULT) == HIGH ? "NORMAL (OK)"
                                                     : "FAULT DETECTED",
                  g_hardwareMonitor.isAmplifierEnabled() ? "ACTIVE" : "MUTED");
  } else if (cmd.startsWith("vol ")) {
    uint8_t vol = cmd.substring(4).toInt();
    g_configManager.getConfig().volume = vol;
    g_configManager.save();
    g_dspEngine.updateFromConfig(g_configManager.getConfig());
    Serial.printf("[CLI] Volume set to %u%%\n", vol);
  } else if (cmd.equalsIgnoreCase("reset")) {
    g_configManager.resetToDefaults();
    g_dspEngine.updateFromConfig(g_configManager.getConfig());
    Serial.println("[CLI] Reset configuration to defaults.");
  }
}

// ==============================================================================
// SYSTEM INITIALIZATION & MAIN EXECUTION LOOP
// ==============================================================================
void setup() {
  Serial.begin(115200);
  delay(500);
  Serial.println(
      "\n==========================================================");
  Serial.println(" AuraForge 50X - Enterprise High-Fidelity Audio Station ");
  Serial.println(" Hardware Platform: 4-Layer KiCad 10 | TPA3116D2 + TPS61088");
  Serial.println(
      "==========================================================\n");

  // 1. Initialize NVS Configuration Store
  g_configManager.begin();

  // 2. Initialize Hardware Protection & Power Monitor (Closed-Loop Thermal
  // Governor)
  g_hardwareMonitor.begin();

  // 3. Initialize 10-Band Parametric Equalizer, 128-Pt Radix-2 FFT & Audio
  // Engine
  g_dspEngine.begin();
  g_dspEngine.updateFromConfig(g_configManager.getConfig());

  // 4. Initialize Wi-Fi Manager, Captive Portal & mDNS Responder
  g_wifiManager.begin(g_configManager.getConfig());

  // 4b. Initialize Wi-Fi CSI Motion Sensing & Presence State Machine
  g_csiRadarEngine.begin();

  // 5. Initialize Async HTTP Server, Dual-Bank OTA & WebSocket Telemetry
  g_webServerModule.begin();

  // 6. Configure I2S Settings for High-Fidelity Output
  static i2s_config_t i2s_config = {
      .mode = (i2s_mode_t)(I2S_MODE_MASTER | I2S_MODE_TX),
      .sample_rate = DSP_SAMPLE_RATE,
      .bits_per_sample = I2S_BITS_PER_SAMPLE_16BIT,
      .channel_format = I2S_CHANNEL_FMT_RIGHT_LEFT,
      .communication_format = I2S_COMM_FORMAT_STAND_MSB,
      .intr_alloc_flags = ESP_INTR_FLAG_LEVEL1,
      .dma_buf_count = 8,
      .dma_buf_len = 128,
      .use_apll = false,
      .tx_desc_auto_clear = true};

  a2dp_sink = new BluetoothA2DPSink();
  a2dp_sink->set_i2s_config(i2s_config);
  a2dp_sink->set_stream_reader(audioDataCallback, false);
  a2dp_sink->set_on_connection_state_changed(avrcpStateCallback);

  // 7. Start Bluetooth A2DP Sink
  Serial.printf(
      "[AuraForge 50X] Initializing Audio Engine & Bluetooth '%s'...\n",
      g_configManager.getConfig().btDeviceName);
  if (btStart()) {
    a2dp_sink->start(g_configManager.getConfig().btDeviceName);
    Serial.printf("[AuraForge 50X] Bluetooth Advertising as '%s'...\n",
                  g_configManager.getConfig().btDeviceName);
  }

  // 8. Enable TPA3116D2 Power Output with Anti-Pop Sequencing
  g_hardwareMonitor.setAmplifierState(true);
}

void loop() {
  handleSerialCommands();
  g_hardwareMonitor.update();
  g_csiRadarEngine.update();
  g_wifiManager.update();
  g_webServerModule.update();

  vTaskDelay(pdMS_TO_TICKS(10));
}

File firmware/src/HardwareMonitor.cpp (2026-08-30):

/**
 * @file HardwareMonitor.cpp
 * @brief AuraForge 50X - Closed-Loop Thermal & Digital Governor, Amplifier
 * Fault Protection & Power Monitor Implementation
 * @author Ravi Kachhwaha
 */

#include "HardwareMonitor.h"
#include "ConfigManager.h"
#include "DspEngine.h"
#include <ArduinoJson.h>

HardwareMonitor g_hardwareMonitor;

HardwareMonitor::HardwareMonitor() {}

void HardwareMonitor::begin() {
  pinMode(PIN_AMP_SDZ, OUTPUT);
  pinMode(PIN_STATUS_LED, OUTPUT);
  pinMode(PIN_AMP_FAULT, INPUT_PULLUP);

  // Initial state: Start muted to prevent startup pop transients
  digitalWrite(PIN_AMP_SDZ, LOW);
  digitalWrite(PIN_STATUS_LED, LOW);
  telemetry.ampEnabled = false;

  telemetry.cpuFreqMHz = ESP.getCpuFreqMHz();
  telemetry.chipRevision = ESP.getChipRevision();

  // Initial silicon temperature reading
  float rawTemp = temperatureRead();
  if (rawTemp > 0.0f && rawTemp < 130.0f) {
    telemetry.temperatureC = rawTemp;
    telemetry.temperatureF = rawTemp * 1.8f + 32.0f;
  }

  Serial.printf("[Hardware Monitor] Subsystem initialized. Silicon Temp: "
                "%.1f°C | CPU: %u MHz\n",
                telemetry.temperatureC, telemetry.cpuFreqMHz);
}

void HardwareMonitor::setAmplifierState(bool enable) {
  if (enable) {
    if (digitalRead(PIN_AMP_FAULT) == LOW) {
      Serial.println("[HARDWARE PROTECTION] Cannot enable TPA3116D2 - Active "
                     "FAULT line low!");
      telemetry.ampFaultDetected = true;
      setLedMode(LED_FAST_BLINK);
      return;
    }
    delay(100); // 100ms Anti-pop delay allowing TPS61088 21V rail to charge
    digitalWrite(PIN_AMP_SDZ, HIGH);
    telemetry.ampEnabled = true;
    telemetry.ampFaultDetected = false;
    Serial.println("[AuraForge 50X] TPA3116D2 Amplifier Output Unmuted.");
  } else {
    digitalWrite(PIN_AMP_SDZ, LOW);
    telemetry.ampEnabled = false;
    Serial.println("[AuraForge 50X] TPA3116D2 Amplifier Output Muted.");
  }
}

void HardwareMonitor::setLedMode(LedMode mode) { currentLedMode = mode; }

void HardwareMonitor::handleLedPatterns() {
  unsigned long now = millis();
  uint32_t interval = 500;

  switch (currentLedMode) {
  case LED_OFF:
    digitalWrite(PIN_STATUS_LED, LOW);
    return;
  case LED_ON:
    digitalWrite(PIN_STATUS_LED, HIGH);
    return;
  case LED_SLOW_BLINK:
    interval = 500;
    break;
  case LED_FAST_BLINK:
    interval = 100;
    break;
  case LED_HEARTBEAT:
    interval = 1000;
    break;
  }

  if (now - lastLedToggle >= interval) {
    lastLedToggle = now;
    ledState = !ledState;
    digitalWrite(PIN_STATUS_LED, ledState ? HIGH : LOW);
  }
}

void HardwareMonitor::updateTelemetry() {
  unsigned long now = millis();
  if (now - lastUptimeTick >= 1000) {
    lastUptimeTick = now;
    telemetry.uptimeSeconds++;
    telemetry.freeHeapBytes = ESP.getFreeHeap();
  }
}

void HardwareMonitor::processThermalGovernor() {
  unsigned long now = millis();
  if (now - tempCheckTimer < 250)
    return; // 4 Hz Thermal Governor Execution Loop
  tempCheckTimer = now;

  // Read on-chip silicon junction temperature
  float rawTemp = temperatureRead();
  if (rawTemp > 0.0f && rawTemp < 130.0f) {
    // Exponential Moving Average filter (alpha = 0.15) for smooth thermal
    // telemetry
    telemetry.temperatureC = telemetry.temperatureC * 0.85f + rawTemp * 0.15f;
    telemetry.temperatureF = telemetry.temperatureC * 1.8f + 32.0f;
  }

  const SystemConfig &cfg = g_configManager.getConfig();
  telemetry.governorActive = cfg.thermalGovernorEnabled;

  if (!cfg.thermalGovernorEnabled) {
    telemetry.governorState = GOVERNOR_NORMAL;
    telemetry.thermalAttenuation_dB = 0.0f;
    telemetry.thermalGainMultiplier = 1.0f;
    g_dspEngine.setThermalGovernorGain(1.0f);
    return;
  }

  float t = telemetry.temperatureC;
  float throtLimit = cfg.thermalThrottlingTemp; // e.g. 75.0°C
  float critLimit = cfg.thermalCriticalTemp;    // e.g. 85.0°C

  if (t >= critLimit) {
    // Critical Tier: -6.0 dB digital attenuation (0.501 multiplier)
    telemetry.governorState = GOVERNOR_CRITICAL;
    telemetry.thermalAttenuation_dB = -6.0f;
    telemetry.thermalGainMultiplier = 0.501f;
    setLedMode(LED_FAST_BLINK);
  } else if (t >= throtLimit) {
    // Throttled Tier: -3.0 dB digital foldback (0.708 multiplier)
    telemetry.governorState = GOVERNOR_THROTTLED;
    telemetry.thermalAttenuation_dB = -3.0f;
    telemetry.thermalGainMultiplier = 0.708f;
  } else if (t >= (throtLimit - 10.0f)) {
    // Warm Warning Tier: -1.0 dB soft limiter reduction (0.891 multiplier)
    telemetry.governorState = GOVERNOR_WARM;
    telemetry.thermalAttenuation_dB = -1.0f;
    telemetry.thermalGainMultiplier = 0.891f;
  } else {
    // Normal Safe Tier: Full Dynamics (1.000 multiplier, 0 dB attenuation)
    telemetry.governorState = GOVERNOR_NORMAL;
    telemetry.thermalAttenuation_dB = 0.0f;
    telemetry.thermalGainMultiplier = 1.0f;
  }
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

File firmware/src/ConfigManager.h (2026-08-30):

/**
 * @file ConfigManager.h
 * @brief AuraForge 50X - Non-Volatile Storage (NVS) Configuration Manager
 * @author Ravi Kachhwaha
 */

#ifndef CONFIG_MANAGER_H
#define CONFIG_MANAGER_H

#include <Arduino.h>
#include <Preferences.h>
#include <ArduinoJson.h>

#define NUM_EQ_BANDS 10
#define NUM_USER_PRESETS 4

struct UserPreset {
    char name[24] = "Custom Slot";
    float eqGains[NUM_EQ_BANDS] = {0.0f, 0.0f, 0.0f, 0.0f, 0.0f, 0.0f, 0.0f, 0.0f, 0.0f, 0.0f};
    bool isSet = false;
};

struct SystemConfig {
    // Audio / DSP Settings
    uint8_t volume = 80;
    bool isMuted = false;
    float eqGains[NUM_EQ_BANDS] = {0.0f, 0.0f, 0.0f, 0.0f, 0.0f, 0.0f, 0.0f, 0.0f, 0.0f, 0.0f};
    float preAmpGain = 0.0f;           // -12dB to +12dB
    float balance = 0.0f;              // -1.0 (Left) to +1.0 (Right)
    bool monoMode = false;             // Downmix to mono
    bool phaseInvertL = false;
    bool phaseInvertR = false;
    float dynamicBassGain = 3.0f;      // 0.0 to 12.0 dB
    float dynamicBassFreq = 80.0f;     // 40Hz to 150Hz
    bool dynamicBassEnabled = true;
    float stereoWidth = 1.0f;          // 0.0 (Mono) to 2.0 (Ultra-wide)
    float highPassCutoff = 20.0f;      // 20Hz - 100Hz
    float subLowPassCutoff = 150.0f;   // 60Hz - 250Hz
    bool loudnessCompensation = false;

    // Dynamic Range Compressor (DRC) Settings
    float drcThreshold = -18.0f;       // -40dB to 0dB
    float drcRatio = 4.0f;             // 1.0 to 20.0

    // Closed-Loop Thermal & Digital Governor
    bool thermalGovernorEnabled = true;
    float thermalThrottlingTemp = 75.0f; // °C trigger threshold
    float thermalCriticalTemp = 85.0f;   // °C critical shutdown/attenuation

    // Network & Wi-Fi Settings
    char wifiStaSsid[32] = "";
    char wifiStaPass[64] = "";
    char wifiApSsid[32] = "AuraForge-50X-AP";
    char wifiApPass[64] = "auraforge123";
    bool wifiApEnabled = true;
    bool useStaticIp = false;
    char staticIp[16] = "192.168.1.200";
    char staticGateway[16] = "192.168.1.1";
    char staticSubnet[16] = "255.255.255.0";
    char mdnsHost[32] = "auraforge50x";

    // Bluetooth & System Settings
    char btDeviceName[32] = "AuraForge-50X-Audio";
    bool nightMode = false;
    uint16_t autoStandbyMinutes = 15;
    char adminPassword[32] = "admin";
    uint32_t bootCount = 0;

    // Wi-Fi CSI Motion Sensing & Spatial Presence State Machine
    bool csiStreamingEnabled = false;
    char csiPcIp[32] = "192.168.4.2";  // Target PC IP for RuView UDP stream
    uint16_t csiPcPort = 5000;         // Target UDP Port for RuView
    uint8_t csiStreamRateHz = 50;      // UDP Stream Rate (10, 25, 50, 100 Hz)
    bool csiPresenceAutomation = false;
    float csiSensitivity = 5.0f;       // Variance sensitivity threshold
    uint16_t csiTimeoutSeconds = 120;  // Auto-vacant cooldown seconds
    bool csiAutoMute = false;          // Auto-mute when vacant
    bool csiAutoPlay = false;          // Auto-unmute on occupancy

    // Themes & Hardware Power
    uint8_t activeTheme = 0;           // 0..7 Cyberpunk Themes
    uint8_t powerProfile = 0;          // 0: High Perf (240MHz), 1: Balanced (160MHz), 2: Eco (80MHz)

    // User Custom Preset Slots
    UserPreset userPresets[NUM_USER_PRESETS];
};

class ConfigManager {
public:
    ConfigManager();
    bool begin();
    void load();
    void save();
    void resetToDefaults();

    SystemConfig& getConfig() { return config; }
    const SystemConfig& getConfig() const { return config; }
    
    // NVS User Preset Management
    bool saveUserPreset(uint8_t slot, const char* name, const float* gains);
    bool loadUserPreset(uint8_t slot, float* gains);
    String getUserPresetsJson();

    // JSON Serialization for Web UI & REST API
    String toJsonString();
    bool updateFromJson(const JsonDocument& doc);

private:
    Preferences preferences;
    SystemConfig config;
};

extern ConfigManager g_configManager;

#endif // CONFIG_MANAGER_H

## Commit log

2026-08-25 Revise README for clarity and additional details
    Updated project description for clarity and added details about the USB-to-UART bridge functionality. Revised sections on firmware flashing and audio output validation.
2026-08-25 Revise funding estimates in README.md
    Updated cost estimates for PCB fabrication and components in the Grant Budget Justification section.
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2026-08-26 Revise component details in AuraForge_50X.csv
    Updated component specifications and descriptions in the AuraForge_50X CSV file.
    [AuraForge_50X.csv]
2026-08-26 Revise budget justification for PCB costs and components
    Updated cost estimates for PCB fabrication and components in the budget justification section.
2026-08-26 Update hardware files with new one's.
    [AuraForge_50X.kicad_pcb]
2026-08-26 Firmware Update to make best
    [partitions.csv]
2026-08-27 bom.csv added
    [bom.csv]
2026-08-28 Revise BOM format to add supplier and pricing details
    Updated BOM file to include supplier and pricing information.
    [bom.csv]
2026-08-29 Revise BOM structure with additional details
    Updated BOM format to include new columns for footprint and LCSC part numbers.
    [bom.csv]
2026-08-29 Enhance README with new features and budget details
    Updated project description and added new features including Wi-Fi CSI sensing and DSP capabilities. Revised grant budget justification and detailed manufacturing costs for a 3-board prototype run.
2026-08-29 Fix formatting and update BOM in README.md
    Corrected formatting issues in the hardware subsystem architecture and added advanced software capabilities section. Updated the Bill of Materials with pricing and component details.
2026-08-29 Revise grant budget justification and details
    Updated grant budget justification and detailed budget breakdown for the 3-board turnkey PCBA prototype run.
2026-08-29 Upload updated files.
    [AuraForge_50X-B_Cu.gbl, AuraForge_50X-B_Mask.gbs, AuraForge_50X-B_Silkscreen.gbo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]
2026-08-30 Fix formatting issue in components_bom.csv
    [components_bom.csv]
2026-08-30 Add BOM for AuraForge 50X Prototype Kit
    Added a bill of materials for the AuraForge 50X Prototype Kit, including details on components, pricing, and suppliers.
    [bom.csv]
2026-08-30 Revise BOM with new components and updated totals
    Updated the bill of materials with new items and adjusted totals.
    [bom.csv]
2026-08-30 Revise BOM with updated item details and totals
    Updated BOM with new quantities and descriptions for components.
    [bom.csv]
2026-08-30 Revise Acoustic Transducers description and TOTAL line
    Updated description for Acoustic Transducers and modified the TOTAL line to reflect changes in the BOM.
    [bom.csv]
2026-08-30 Revise README with BOM and assembly instructions
    Updated the README to include a detailed Bill of Materials (BOM) section and revised assembly instructions for the AuraForge 50X hardware.
2026-08-30 Uploaded updated files
    [partitions.csv]
2026-08-30 Modify item details in bom.csv
    Updated descriptions and item details for Battery Power and Acoustic Transducers.
    [bom.csv]
2026-08-31 Revise power stage details in README.md
    Updated power stage description and specifications for clarity.
2026-08-31 Change R9 resistance value from 165k to 91k
    Updated the resistance value for R9 from 165k to 91k and adjusted the corresponding URL.
    [components_bom.csv]
2026-08-31 Upload updated and fixed files.
    [AuraForge_50X-B_Cu.gbl, AuraForge_50X-B_Mask.gbs, AuraForge_50X-B_Silkscreen.gbo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]
2026-09-04 Revise components_bom.csv with detailed descriptions
    Updated components_bom.csv to add descriptions for each component and changed the header format.
    [components_bom.csv]
2026-09-05 Update README for clarity and technical details
    Revised project description for clarity and conciseness. Updated technical specifications and assembly instructions for better understanding.
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2026-09-11 Fix image link case sensitivity in README
2026-09-11 Refactor BOM table in README.md
    Updated BOM table with formatted links and corrected entries.
2026-09-13 Fix total cost in BOM section
    Updated the total cost in the BOM section of the README.
2026-09-15 Uploaded latest PCB files.
    [AuraForge_50X-B_Cu.gbl, AuraForge_50X-B_Mask.gbs, AuraForge_50X-B_Silkscreen.gbo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]
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2026-09-15 Revise BOM with updated quantities and pricing
    Updated BOM with new quantities and total prices, including discounts for components.
    [bom.csv]
2026-09-15 Adjust total in bom.csv for prototype kit costs
    Updated total cost for the Complete AuraForge 50X Prototype Kit.
    [bom.csv]
2026-09-23 Uploading latest files of New PCB Layout
    [AuraForge_50X-B_Cu.gbl, AuraForge_50X-B_Mask.gbs, AuraForge_50X-B_Silkscreen.gbo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]
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2026-09-24 Latest PCB files uploaded
    [AuraForge_50X.kicad_pcb, AuraForge_50X.kicad_sch]
2026-09-24 Latest PCB file's uploaded
    [AuraForge_50X-B_Cu.gbl, AuraForge_50X-B_Mask.gbs, AuraForge_50X-B_Silkscreen.gbo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]
2026-09-24 Latest PCB 3D files uploaded
    [AuraForge_50X.step]
2026-09-24 Latest PCB 3D file's uploaded
    [AuraForge_50X-compressed.stl]
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2026-10-02 Revise BOM quantities and total costs in README
    Updated BOM details including quantities and costs for components. and replace some things with low cost to get more amount for components and other thing like cable and etc will be at lowest cost.
2026-10-02 Fix BOM component costs and links
    Updated BOM with revised costs for components.
2026-10-02 Revise BOM with new quantities and pricing
    Updated quantities and prices for various items in the BOM.
    [bom.csv]
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2026-10-07 name change to bom_old.csv
    [bom_old.csv]
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2026-10-08 Uploaded all latest files after PCB design update
    [AuraForge_50X - old.kicad_pcb, AuraForge_50X.kicad_sch]
2026-10-08 Uploaded latest 3D files after PCB design update
    [AuraForge_50X-compressed.stl, AuraForge_50X.step]
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2026-10-09 Fix typo in power supply cable description
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2026-10-13 Replace image link in README for speaker case
    Updated image link for the 3D view of the speaker case.
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2026-10-20 Uploaded latest and fixed 3D files for printing
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
